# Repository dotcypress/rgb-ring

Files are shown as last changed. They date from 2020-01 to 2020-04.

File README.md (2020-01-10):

# RGB Ring

Rust powered RGB light ring.

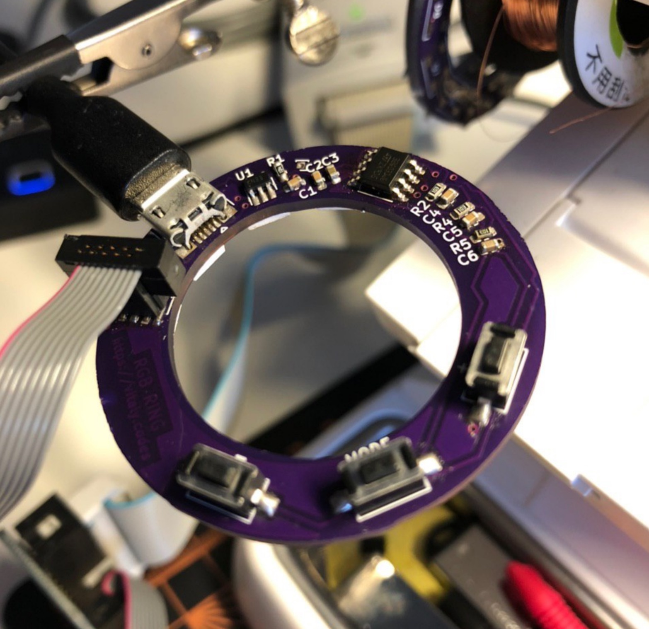
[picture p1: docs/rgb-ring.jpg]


## Resources

- [Firmware(WIP)](firmware/)
- [PCB(KiCad project)](pcb/)
- [Gerber files](docs/fabrication.zip)
- [Schematics](docs/rgb-ring-schematics.pdf)

## License

Licensed under either of

- Apache License, Version 2.0 ([LICENSE-APACHE](LICENSE-APACHE) or
  http://www.apache.org/licenses/LICENSE-2.0)
- MIT license ([LICENSE-MIT](LICENSE-MIT) or http://opensource.org/licenses/MIT)

at your option.

### Contribution

Unless you explicitly state otherwise, any contribution intentionally submitted
for inclusion in the work by you, as defined in the Apache-2.0 license, shall be
dual licensed as above, without any additional terms or conditions.

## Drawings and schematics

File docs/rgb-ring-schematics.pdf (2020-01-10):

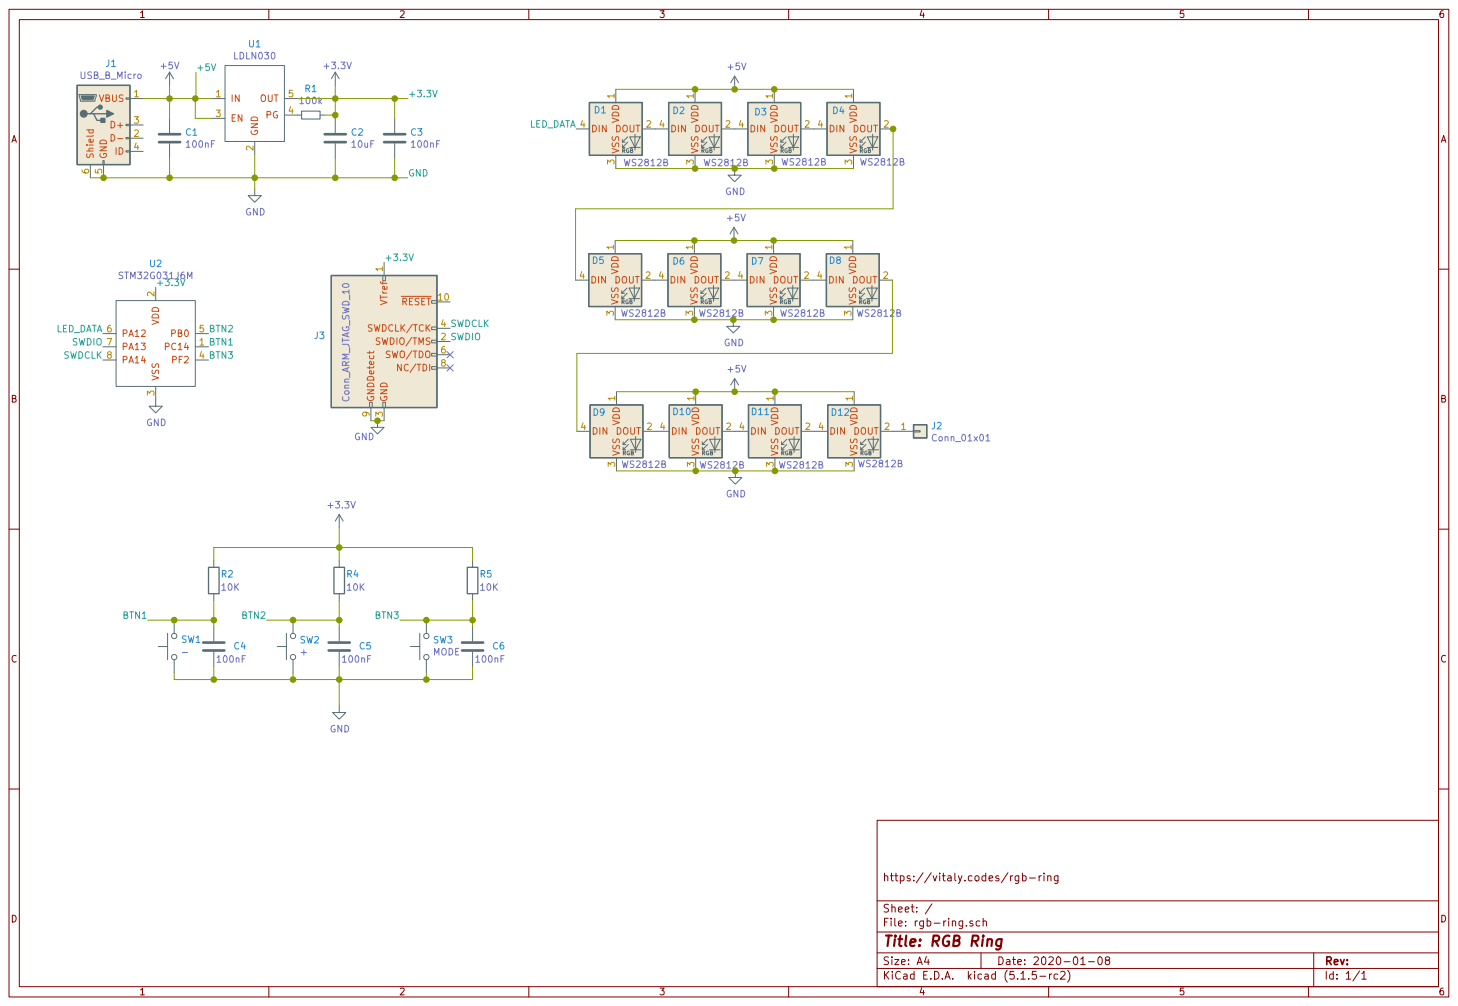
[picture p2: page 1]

3 PF2 4 PB0 5 PA12 6 PA13 7 PA14 8 U2 STM32G031J6M VTref 1 RESET 10 SWDIO/TMS 2 GND

3 SWDCLK/TCK 4 SWO/TDO 6 NC/TDI 8 GNDDetect 9

File: rgb-ring.sch Sheet: / https://vitaly.codes/rgb-ring

Id: 1/1 Title: RGB Ring

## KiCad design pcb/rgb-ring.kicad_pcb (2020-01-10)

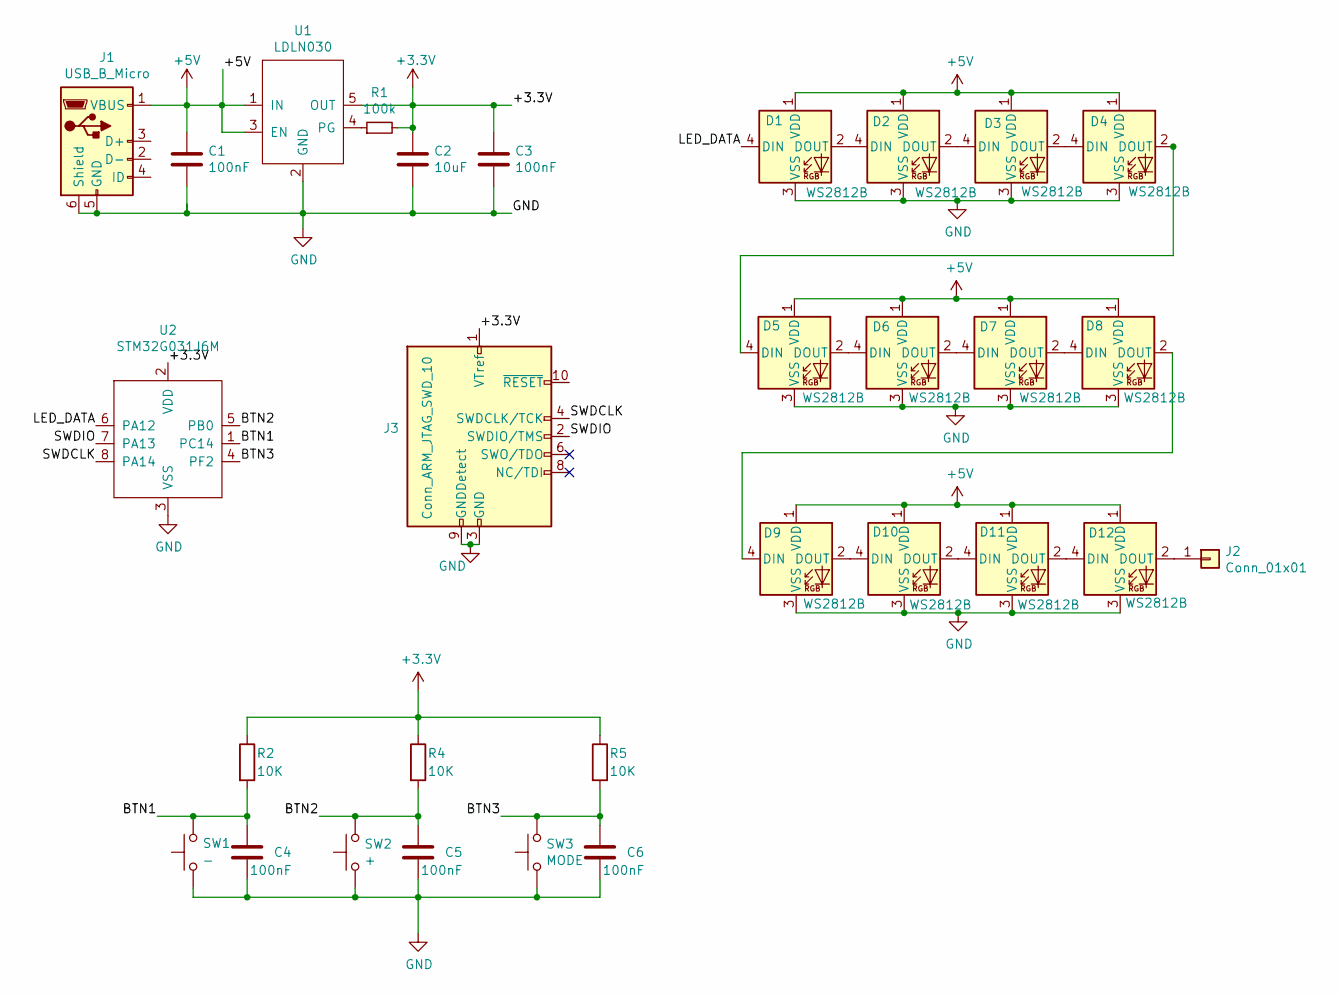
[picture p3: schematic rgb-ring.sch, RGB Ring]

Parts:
C1, C3, C4, C5, C6: 100nF; C_0603_1608Metric
C2: 10uF; C_0603_1608Metric
D1, D2, D3, D4, D5, D6, D7, D8, D9, D10, D11, D12: WS2812B; LED_WS2812B_PLCC4_5.0x5.0mm_P3.2mm
J1: USB_B_Micro; USB_Micro-B_Amphenol_10103594-0001LF_Horizontal
J2: Conn_01x01; PinHeader_1x01_P1.00mm_Vertical
J3: Conn_ARM_JTAG_SWD_10; PinHeader_2x05_P1.27mm_Vertical_SMD
R1: 100k; R_0603_1608Metric
R2, R4, R5: 10K; R_0603_1608Metric
SW1: -; SW_SPST_CK_RS282G05A3
SW2: +; SW_SPST_CK_RS282G05A3
SW3: MODE; SW_SPST_CK_RS282G05A3
U1: LDLN030; TSOT-23-5
U2: STM32G031J6M; SO-8_3.9x4.9mm_P1.27mm

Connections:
+3V3: C2.1, C3.1, J3.1 (VTref), R1.2, R2.1, R4.1, R5.1, U1.5 (OUT), U2.2 (VDD)
+5V: C1.1, D1.1 (VDD), D2.1 (VDD), D3.1 (VDD), D4.1 (VDD), D5.1 (VDD), D6.1 (VDD), D7.1 (VDD), D8.1 (VDD), D9.1 (VDD), D10.1 (VDD), D11.1 (VDD), D12.1 (VDD), J1.1 (VBUS), U1.1 (IN), U1.3 (EN)
/BTN1: C4.2, R2.2, SW1.2, U2.1 (PC14)
/BTN2: C5.2, R4.2, SW2.2, U2.5 (PB0)
/BTN3: C6.2, R5.2, SW3.2, U2.4 (PF2)
/LED_DATA: D1.4 (DIN), U2.6 (PA12)
/SWDCLK: J3.4 (SWDCLK/TCK), U2.8 (PA14)
/SWDIO: J3.2 (SWDIO/TMS), U2.7 (PA13)
GND: C1.2, C2.2, C3.2, C4.1, C5.1, C6.1, D1.3 (VSS), D2.3 (VSS), D3.3 (VSS), D4.3 (VSS), D5.3 (VSS), D6.3 (VSS), D7.3 (VSS), D8.3 (VSS), D9.3 (VSS), D10.3 (VSS), D11.3 (VSS), D12.3 (VSS), J1.5 (GND), J1.6 (Shield), J3.3 (GND), J3.5 (GND), J3.9 (GNDDetect), SW1.1, SW2.1, SW3.1, U1.2 (GND), U2.3 (VSS)
unnamed: D1.2 (DOUT), D2.4 (DIN)
unnamed: D2.2 (DOUT), D3.4 (DIN)
unnamed: D3.2 (DOUT), D4.4 (DIN)
unnamed: D4.2 (DOUT), D5.4 (DIN)
unnamed: D5.2 (DOUT), D6.4 (DIN)
unnamed: D6.2 (DOUT), D7.4 (DIN)
unnamed: D7.2 (DOUT), D8.4 (DIN)
unnamed: D8.2 (DOUT), D9.4 (DIN)
unnamed: D10.2 (DOUT), D11.4 (DIN)
unnamed: D9.2 (DOUT), D10.4 (DIN)
unnamed: D11.2 (DOUT), D12.4 (DIN)
unnamed: D12.2 (DOUT), J2.1
unnamed: R1.1, U1.4 (PG)

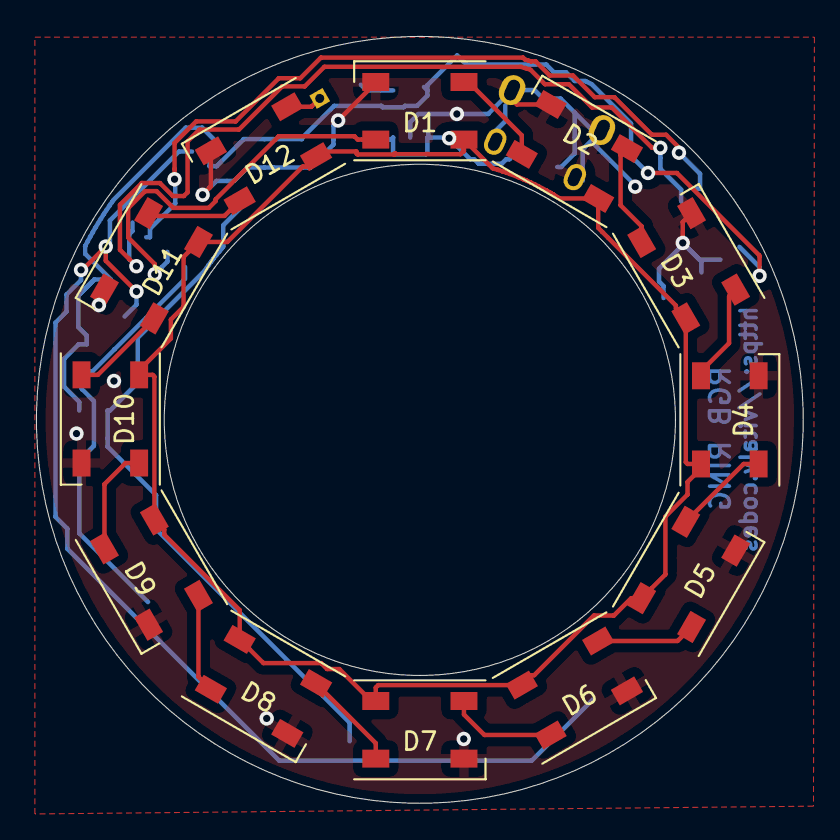
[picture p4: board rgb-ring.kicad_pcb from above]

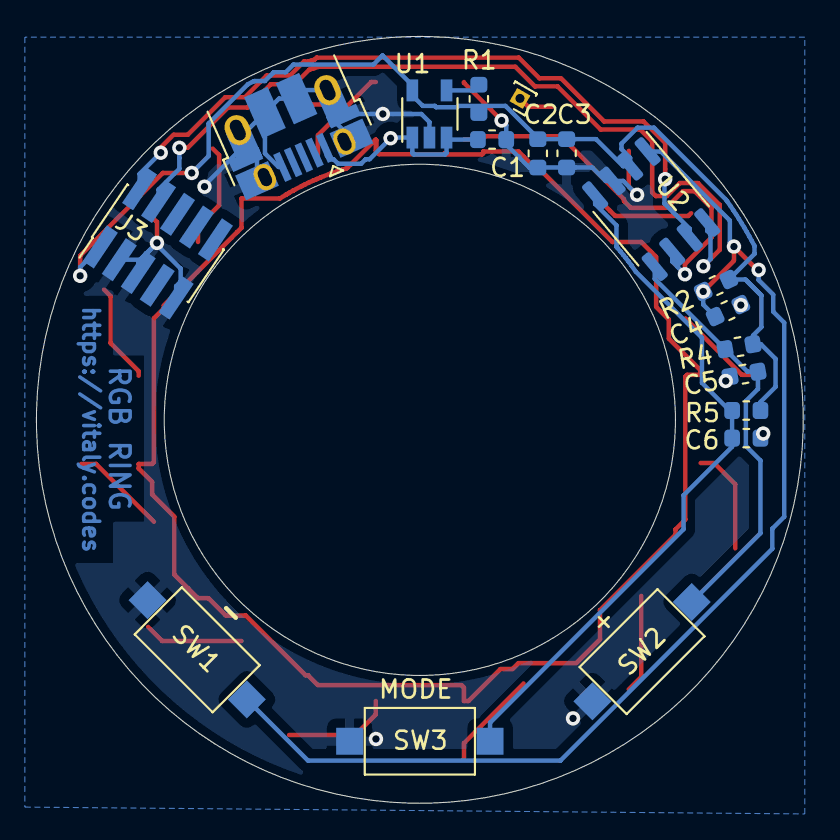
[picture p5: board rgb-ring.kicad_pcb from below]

Board: 2 copper layers, 42.6 x 42.6 mm, 30 parts (18 on the bottom side), 22 nets.

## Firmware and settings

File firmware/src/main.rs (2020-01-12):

#![no_std]
#![no_main]
#![deny(warnings)]

extern crate panic_halt;
extern crate rtfm;
extern crate stm32g0xx_hal as hal;

mod ring;
mod palette;

use hal::exti::Event;
use hal::gpio::*;
use hal::prelude::*;
use hal::rcc::{self, PllConfig};
use hal::spi;
use hal::stm32;
use hal::timer;
use ring::{RGBRing, ControlEvent};
use rtfm::app;

type LedTimer = timer::Timer<stm32::TIM17>;
type SPIBus = spi::Spi<stm32::SPI1, (spi::NoSck, spi::NoMiso, gpioa::PA12<Input<Floating>>)>;
type Ring = RGBRing<SPIBus>;

#[app(device = hal::stm32, peripherals = true)]
const APP: () = {
    struct Resources {
        ring: Ring,
        timer: LedTimer,
        exti: stm32::EXTI,
    }

    #[init]
    fn init(ctx: init::Context) -> init::LateResources {
        let pll_cfg = PllConfig::with_hsi(4, 24, 2);
        let rcc_cfg = rcc::Config::pll().pll_cfg(pll_cfg);
        let mut rcc = ctx.device.RCC.freeze(rcc_cfg);
        rcc.set_reset_mode(rcc::ResetMode::GPIO);

        let port_a = ctx.device.GPIOA.split(&mut rcc);
        let port_b = ctx.device.GPIOB.split(&mut rcc);
        let port_c = ctx.device.GPIOC.split(&mut rcc);
        let port_f = ctx.device.GPIOF.split(&mut rcc);

        let spi = ctx.device.SPI1.spi(
            (spi::NoSck, spi::NoMiso, port_a.pa12),
            spi::MODE_0,
            3.mhz(),
            &mut rcc,
        );
        let ring = RGBRing::new(spi);

        let mut exti = ctx.device.EXTI;
        port_f.pf2.listen(SignalEdge::Rising, &mut exti);
        port_c.pc14.listen(SignalEdge::Rising, &mut exti);
        port_b.pb0.listen(SignalEdge::Rising, &mut exti);

        let mut timer = ctx.device.TIM17.timer(&mut rcc);
        timer.start(ring::FPS);
        timer.listen();

        init::LateResources { exti, timer, ring }
    }

    #[task(binds = TIM17, resources = [timer, ring])]
    fn timer_tick(ctx: timer_tick::Context) {
        ctx.resources.ring.refresh();
        ctx.resources.timer.clear_irq();
    }

    #[task(binds = EXTI0_1, resources = [exti, ring])]
    fn btn_plus_click(ctx: btn_plus_click::Context) {
        ctx.resources.ring.handle_event(ControlEvent::Plus);
        ctx.resources.exti.unpend(Event::GPIO0);
    }

    #[task(binds = EXTI2_3, resources = [exti, ring])]
    fn btn_mode_click(ctx: btn_mode_click::Context) {
        ctx.resources.ring.handle_event(ControlEvent::Mode);
        ctx.resources.exti.unpend(Event::GPIO2);
    }

    #[task(binds = EXTI4_15, resources = [exti, ring])]
    fn btn_minus_click(ctx: btn_minus_click::Context) {
        ctx.resources.ring.handle_event(ControlEvent::Minus);
        ctx.resources.exti.unpend(Event::GPIO14);
    }
};

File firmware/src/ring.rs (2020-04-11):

use core::cmp::{max, min};
use hal::hal::spi::FullDuplex;
use smart_leds::SmartLedsWrite;
use smart_leds::RGB8;
use ws2812_spi::Ws2812;

use crate::hal::time::Hertz;
use crate::palette;

const LEDS: usize = 12;
pub const FPS: Hertz = Hertz(50);

pub enum ControlEvent {
    Mode,
    Plus,
    Minus,
}

pub struct RGBRing<SPI> {
    link: Ws2812<SPI>,
    mode: Mode,
    anim: Animation,
    frame: usize,
    luma: usize,
    temp: usize,
    sectors: usize,
    angle: usize,
}

#[derive(Clone, Copy)]
enum Mode {
    Luma,
    Sector,
    Rotation,
    Temp,
}

#[derive(Clone, Copy)]
enum Animation {
    Main,
    Ignition,
    Intro(Mode),
}

impl<SPI> RGBRing<SPI>
where
    SPI: FullDuplex<u8>,
{
    pub fn new(spi: SPI) -> RGBRing<SPI> {
        RGBRing {
            link: Ws2812::new(spi),
            mode: Mode::Luma,
            angle: 0,
            sectors: LEDS,
            luma: 0,
            temp: 5,
            frame: 0,
            anim: Animation::Ignition,
        }
    }

    pub fn handle_event(&mut self, ev: ControlEvent) {
        match self.mode {
            Mode::Luma => match ev {
                ControlEvent::Plus => self.luma = min(7, self.luma + 1),
                ControlEvent::Minus => self.luma = self.luma.saturating_sub(1),
                ControlEvent::Mode => self.switch_to_mode(Mode::Sector),
            },
            Mode::Temp => match ev {
                ControlEvent::Plus => self.temp = min(7, self.temp + 1),
                ControlEvent::Minus => self.temp = self.temp.saturating_sub(1),
                ControlEvent::Mode => self.switch_to_mode(Mode::Luma),
            },
            Mode::Sector => match ev {
                ControlEvent::Plus => self.sectors = min(LEDS, self.sectors + 1),
                ControlEvent::Minus => self.sectors = max(1, self.sectors.saturating_sub(1)),
                ControlEvent::Mode => match self.sectors {
                    LEDS => self.switch_to_mode(Mode::Temp),
                    _ => self.switch_to_mode(Mode::Rotation),
                },
            },
            Mode::Rotation => match ev {
                ControlEvent::Plus => self.angle = (self.angle + 1) % LEDS,
                ControlEvent::Minus => {
                    self.angle = if self.angle == 0 {
                        LEDS - 1
                    } else {
                        self.angle - 1
                    }
                }
                ControlEvent::Mode => self.switch_to_mode(Mode::Temp),
            },
        }
    }

    pub fn refresh(&mut self) {
        self.frame = self.frame.wrapping_add(1);

        let mut buffer = [RGB8::default(); LEDS];
        let proto = palette::get_color(self.luma, self.temp);
        match &self.anim {
            Animation::Main => {
                for idx in 0..self.sectors {
                    let temp = match self.temp {
                        0 => idx % 2,
                        x => x - idx % 2,
                    };
                    buffer[(self.angle + idx) % LEDS] = palette::get_color(self.luma, temp);
                }
            }
            Animation::Ignition => {
                for (idx, color) in buffer.iter_mut().enumerate() {
                    let luma = (self.frame + idx) / 40;
                    let temp = 7 - (self.frame + idx * 2) / 20;
                    *color = palette::get_color(luma, temp);
                }
            }
            Animation::Intro(mode) => match mode {
                Mode::Luma => {
                   for (index, color) in buffer.iter_mut().enumerate() {
                        let luma = (self.frame + index) % 5;
                        *color = palette::get_color(luma, self.temp);
                    }
                }
                Mode::Sector => {
                    if self.frame <= 20 {
                        let offset = self.frame as usize / 2;
                        for color in buffer.iter_mut().skip(offset) {
                            *color = proto;
                        }
                    } else {
                        let offset = LEDS - ((self.frame as usize - 20) / 2);
                        for color in buffer.iter_mut().skip(offset) {
                            *color = proto;
                        }
                    }
                }
                Mode::Rotation => {
                    if self.frame <= 20 {
                        let offset = self.frame as usize / 2;
                        for color in buffer.iter_mut().skip(offset).take(1) {
                            *color = proto;
                        }
                    } else {
                        let offset = LEDS - ((self.frame as usize - 20) / 2);
                        for color in buffer.iter_mut().skip(offset).take(1) {
                            *color = proto;
                        }
                    }
                }
                Mode::Temp => {
                    for (index, color) in buffer.iter_mut().enumerate() {
                        let temp = (self.frame + index) % 8;
                        *color = palette::get_color(self.luma, temp);
                    }
                }
            },
        }
        if self.frame == 40 {
            self.anim = Animation::Main;
        }
        self.link.write(buffer.iter().cloned()).ok();
    }

    fn switch_to_mode(&mut self, mode: Mode) {
        self.anim = Animation::Intro(mode);
        self.frame = 0;
        self.mode = mode;
    }
}
